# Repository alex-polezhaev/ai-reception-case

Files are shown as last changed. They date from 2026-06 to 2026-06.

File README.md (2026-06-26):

<div align="center">

# 🛎️ AI Reception

**A passive AI receptionist on an ESP32-S3.**
It quietly captures front-desk conversations, transcribes and analyzes them in the cloud, and turns each one into a structured report the manager reviews in a Telegram mini-app.







[Case study](docs/case-study.md) · [Architecture](#-architecture) · [Tech stack](#-tech-stack) · [Hardware](#-hardware--enclosure) · [Build & run](#-build--run) · [Author](#-author)

</div>

<div align="center">
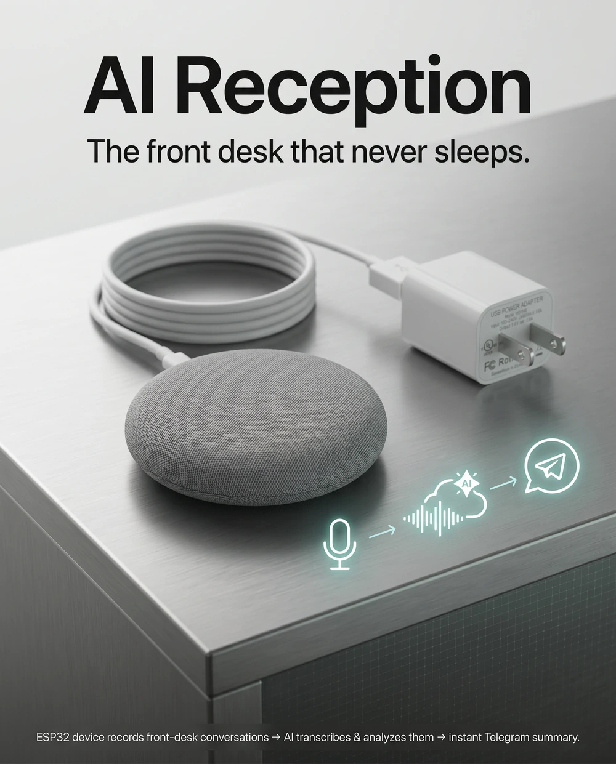
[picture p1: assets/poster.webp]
AI Reception, the front desk that never sleeps

</div>

---

## What it is

**AI Reception** is an end-to-end product: custom **firmware**, a cloud **backend**, and a 3D-printed **enclosure**, built and integrated by one engineer. A small ESP32-S3 device sits on a reception desk with a MEMS microphone. It detects speech on-device, captures audio in short raw-PCM chunks, and uploads them to a Swift/Vapor backend that reconstructs each conversation, transcribes and analyzes it with OpenAI, and presents a clean, structured report to the owner in a Telegram mini-app.

**Why it's interesting**

- 🎙️ **On-device voice activity detection**: the firmware runs an adaptive VAD, so only real speech is buffered and uploaded, never silence.
- 🧩 **Full-stack, multi-discipline**: embedded C++ firmware, a Swift/Vapor microservice backend, a Telegram mini-app, and printable CAD hardware in one coherent system.
- ☁️ **Discrete chunked upload**: fixed-length audio "slots" are POSTed over HTTP and reassembled into sessions server-side, then trimmed with Silero VAD before transcription. No persistent audio stream.
- 🤖 **Cloud AI**: OpenAI Whisper for transcription, an OpenAI LLM for summary and analysis.
- 🛠️ **Real hardware**: a custom 3D-printed round enclosure, shipped as editable CAD source.

---

## 🏗 Architecture

```mermaid
flowchart TB
    subgraph device["🛎️ Reception Device - 3D-printed enclosure"]
        MIC["I2S MEMS Microphone · 16 kHz PCM"]
        ESP["ESP32-S3 Firmware · C++ / PlatformIO<br/>Adaptive VAD · dual AudioSlot buffer"]
        MIC --> ESP
    end

    subgraph core["☁️ Core Backend - Swift / Vapor"]
        API["API Server<br/>JWT auth · POST /device/upload"]
        Q["pgmq message queue"]
        SW["Session Worker<br/>Silero VAD · silence trimming"]
        TW["Transcription Worker"]
        AW["Analysis Worker"]
        MA["Telegram Mini-App<br/>Leaf · HMAC auth"]
        API --> Q --> SW --> TW --> AW --> MA
    end

    STT["Whisper / Transcription"]
    LLM["LLM Analysis & Summary"]
    SB["🗄️ Supabase · Postgres + Auth"]
    S3["🗄️ S3 storage · PCM · WAV buckets"]
    OWNER["👤 Owner / Manager"]

    ESP -- "Wi-Fi · HTTP POST PCM chunks<br/>(per AudioSlot · octet-stream + JWT)" --> API
    ESP -. "silence notifications" .-> API
    API --> S3
    TW --> STT
    AW --> LLM
    API <--> SB
    MA -- "structured report" --> OWNER

    classDef hw fill:#ffe0b2,stroke:#e65100,color:#000;
    classDef ai fill:#e1f5fe,stroke:#0277bd,color:#000;
    class MIC,ESP hw;
    class STT,LLM,SW ai;
```

### How it works

1. **Capture.** The ESP32-S3 reads the I2S MEMS microphone at 16 kHz and fills fixed-length **AudioSlot** PCM buffers. An on-device **adaptive VAD** decides what counts as speech.
2. **Upload.** Each completed slot is sent as a discrete **HTTP POST of raw PCM** to `POST /device/upload/{device_id}` (`application/octet-stream`, `Bearer <JWT>`, with `X-Timestamp` / `X-Sample-Rate` / `X-Sample-Count` headers). Gaps are reported via `POST /device/silence`. *The device uploads chunks; it never holds an open audio stream.*
3. **Sessionize.** The Vapor **API Server** stores chunks in S3 and enqueues them on a Postgres `pgmq` queue. The **Session Worker** groups chunks into sessions and trims silence with **Silero VAD**.
4. **Understand.** The **Transcription Worker** runs **OpenAI Whisper**; the **Analysis Worker** runs an **OpenAI LLM** to produce a structured summary.
5. **Deliver.** The owner opens the **Telegram mini-app** to review a clean, structured report of each conversation.

---

## 🧰 Tech stack

| Layer | Technology |
|---|---|
| **Firmware** | ESP32-S3 · C++ · PlatformIO/Arduino · I2S audio · adaptive VAD · Wi-Fi captive portal |
| **Backend** | Swift · Vapor · async/await · JWT auth · `pgmq` queue |
| **AI** | OpenAI Whisper (transcription) · OpenAI LLM (analysis) · Silero VAD (silence trimming) |
| **Data** | Supabase (Postgres + Auth) · S3-compatible object storage |
| **Interface** | Telegram Bot + Mini-App (Leaf, HMAC auth) |
| **Hardware** | 3D-printed round enclosure (Shapr3D → STEP) |
| **Ops** | Docker Compose · nginx · Dozzle |

---

## 📁 Repository structure

```text
ai-reception-case/
├── firmware/      ESP32-S3 device firmware (C++ / PlatformIO)
├── core/          Swift / Vapor backend: API + workers + Telegram mini-app
├── hardware/      3D-printed round enclosure (STEP) + print notes
├── docs/          Case study (English) + screenshots + demo video
└── assets/        CAD renders and diagrams used in this README
```

---

## 🔩 Hardware & enclosure

The device lives in a custom 3D-printed round enclosure. Editable CAD source (`.step`) lives in [`hardware/`](hardware/).

<div align="center">
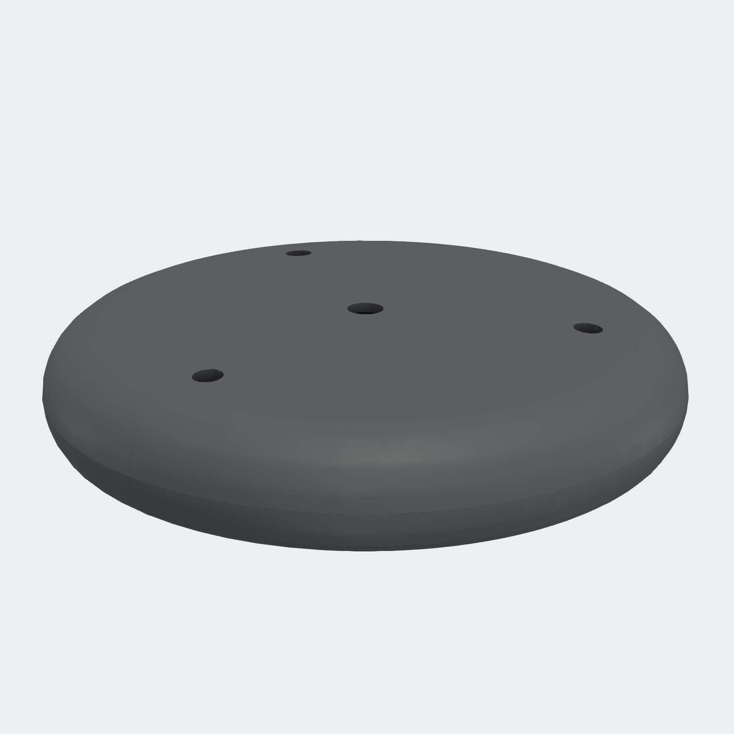
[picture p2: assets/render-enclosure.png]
Round enclosure, assembled

&nbsp;&nbsp;
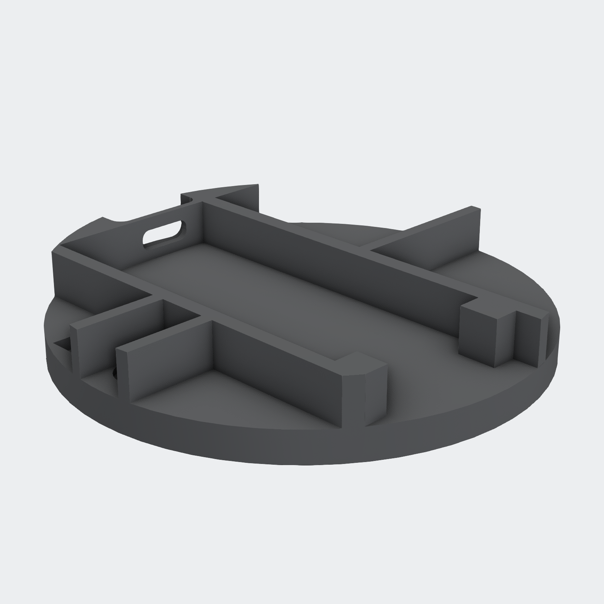
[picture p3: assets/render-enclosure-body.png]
Round enclosure, inside base

<br/>
<sub>The round enclosure (left) and its internal base that holds the board and microphone (right)</sub>
</div>

<div align="center">
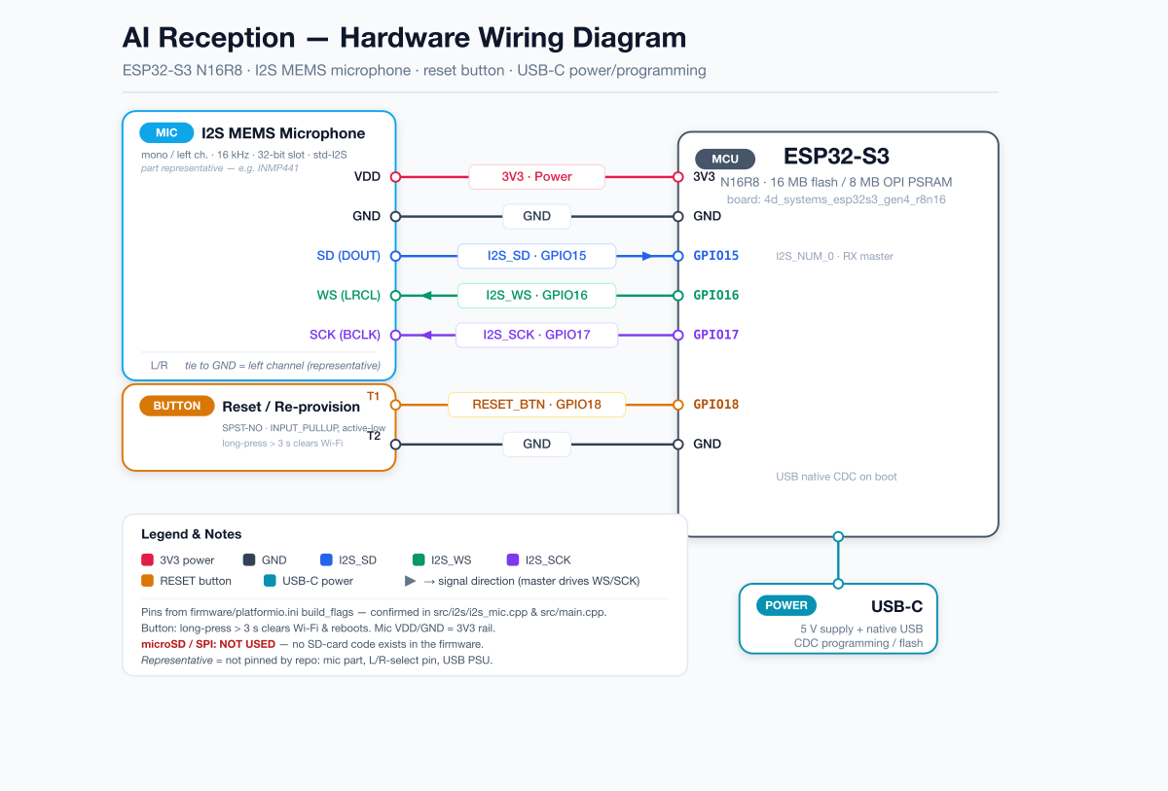
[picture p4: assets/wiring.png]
Hardware wiring diagram

<br/>
<sub>Wiring: I2S MEMS microphone + reset button on the ESP32-S3</sub>
</div>

| Part | File |
|---|---|
| Enclosure body (holds the board &amp; mic) | `hardware/enclosure/mic-v7-main.step` |
| Front cover (microphone hole) | `hardware/enclosure/mic-v7-case-mic-hole.step` |

See [`hardware/README.md`](hardware/README.md) for suggested print settings.

---

## 📸 Screenshots

### The Telegram mini-app

The manager reviews every conversation as a structured report: summary, quality score, keywords, products, audio playback, and the full transcript.

<table>
<tr>
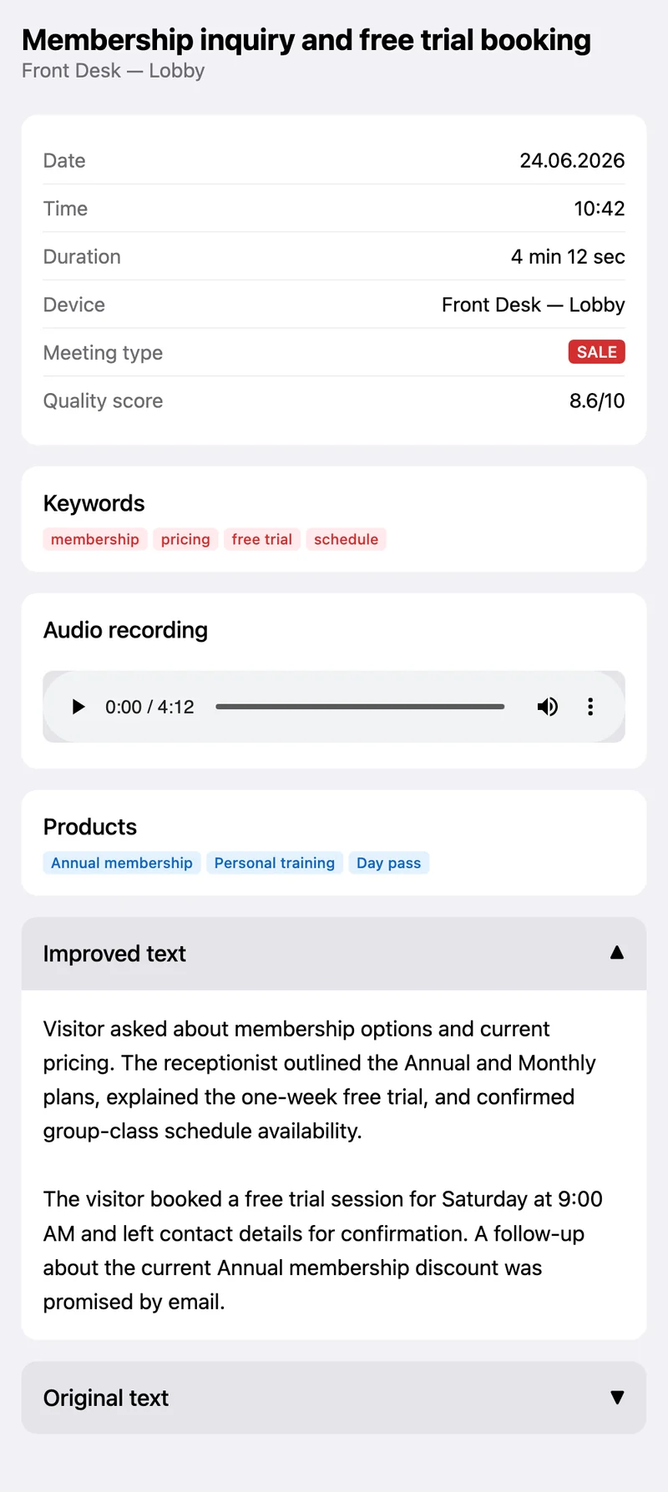
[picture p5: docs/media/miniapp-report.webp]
Session report
<td width="33%"><br/><sub>Session report: summary, quality score, keywords, audio</sub></td>
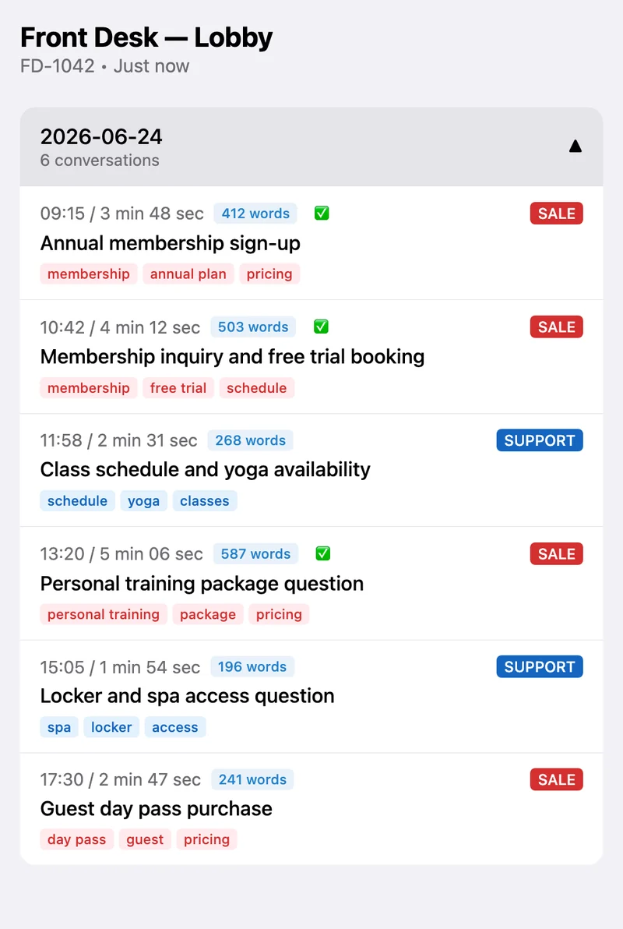
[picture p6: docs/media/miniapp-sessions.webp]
Conversation feed
<td width="33%"><br/><sub>Feed of analyzed conversations</sub></td>
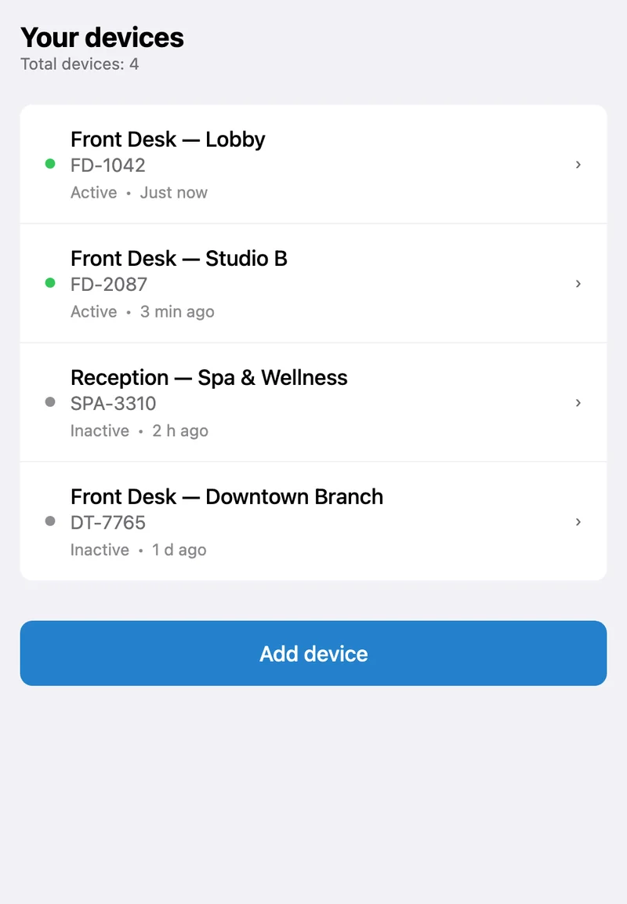
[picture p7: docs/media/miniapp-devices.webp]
Device fleet
<td width="33%"><br/><sub>Device fleet with live status</sub></td>
</tr>
</table>

### Hardware &amp; build

<table>
<tr>
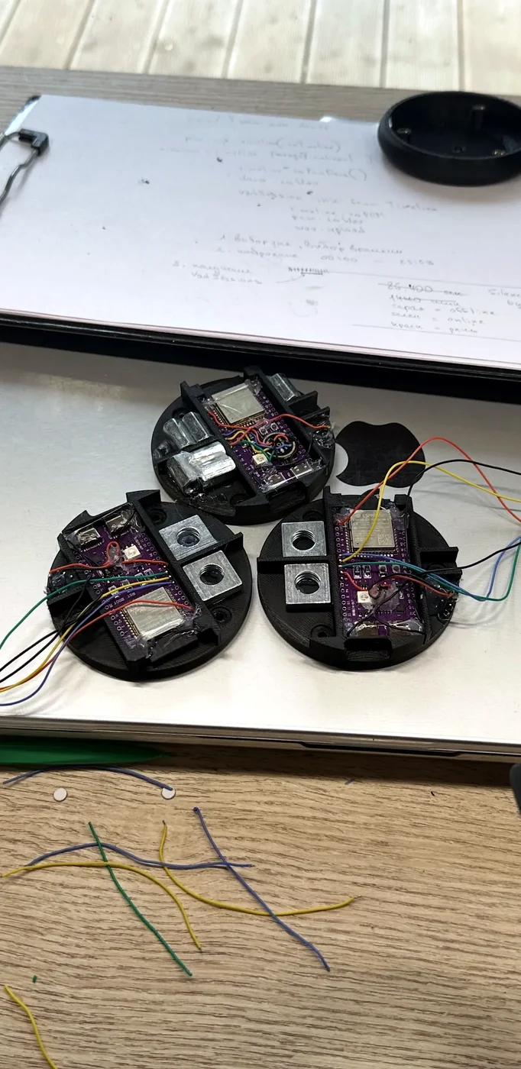
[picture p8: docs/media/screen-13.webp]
ESP32-S3 boards inside the enclosures
<td width="50%"><br/><sub>ESP32-S3 boards inside the printed enclosures</sub></td>
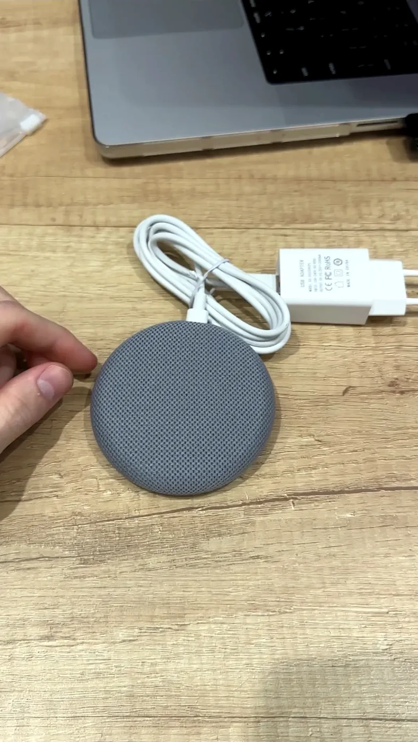
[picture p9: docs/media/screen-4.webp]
Assembled reception unit
<td width="50%"><br/><sub>The assembled reception unit</sub></td>
</tr>
<tr>
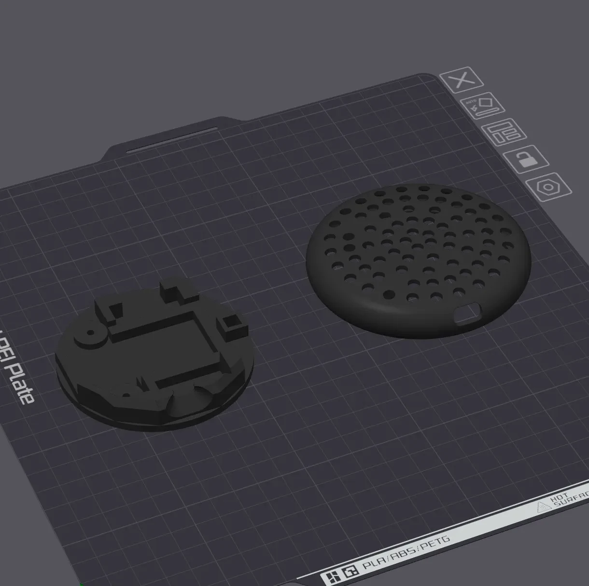
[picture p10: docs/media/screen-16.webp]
Enclosure parts in the slicer
<td width="50%"><br/><sub>Enclosure parts prepared for printing</sub></td>
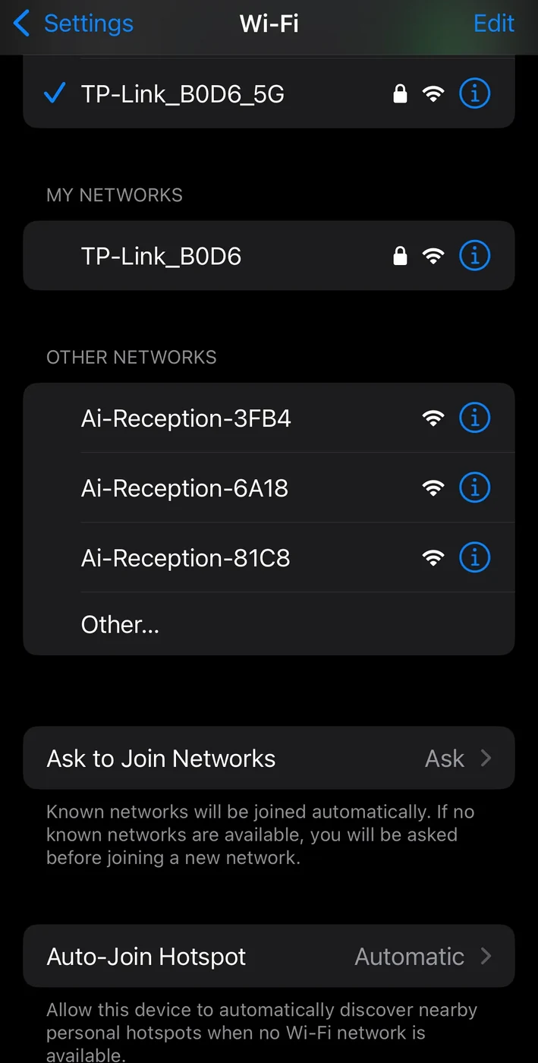
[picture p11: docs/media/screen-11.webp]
Wi-Fi captive-portal setup
<td width="50%"><br/><sub>Captive-portal Wi-Fi setup (<code>Ai-Reception-&lt;id&gt;</code>)</sub></td>
</tr>
</table>

A full walkthrough, including the transcript view, is in the [case study](docs/case-study.md).

---

## 🚀 Build & run

<details>
<summary><b>Firmware: ESP32-S3 (PlatformIO)</b></summary>

```bash
cd firmware
# set your backend URL and device id, then build & flash:
SERVER_URL="https://core.your-domain.example" DEVICE_ID="reception-01" \
  pio run -t upload
```

On first boot the device exposes a Wi-Fi access point (`Ai-Reception`) with a captive portal for entering Wi-Fi credentials. See [`firmware/README.md`](firmware/README.md).
</details>

<details>
<summary><b>Backend: Swift / Vapor (Docker Compose)</b></summary>

```bash
cd core
cp .env.example .env      # fill in OpenAI / Supabase / S3 / Telegram values
make create-network && make docker-build-prod   # build & run the stack
```

Device endpoints: `/device/boot`, `/device/upload`, `/device/silence`, `/device/log`. See [`core/README.md`](core/README.md).
</details>

---

## 🗺 Roadmap

- [x] ESP32-S3 firmware with on-device adaptive VAD
- [x] Discrete chunked PCM upload pipeline
- [x] Swift/Vapor backend: transcription + analysis workers
- [x] Telegram bot + mini-app reports
- [x] 3D-printed round enclosure
- [ ] OTA firmware updates
- [ ] Multi-device fleet dashboard
- [ ] On-device wake-word gating

---

## 🧭 Project evolution

AI Reception went through three hardware generations: a **Gen-1** ESP32 prototype (ESP-IDF / C), an intermediate **Raspberry Pi** attempt, and the current **Gen-2** ESP32-S3 device (PlatformIO / C++) shown here. This repo presents the current system only; earlier branches were retired to keep the design focused.

---

## 📄 License

Released under the [MIT License](LICENSE).

---

## 👤 Author

**Alex Polezhaev**, full-stack & embedded engineer.
I build end-to-end products across firmware, cloud backends, and hardware. **Relocating to the United States, open to roles.**

- GitHub: [@alex-polezhaev](https://github.com/alex-polezhaev)
- Email: polezhaev.advert@gmail.com

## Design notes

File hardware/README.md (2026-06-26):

# Hardware - enclosure

3D-printable parts for the ESP32-S3 reception microphone device: the round enclosure that houses the board and microphone.

## Overview

The physical device is housed in a single round **enclosure** made of two parts: a **body** that holds the ESP32-S3 board and microphone, and a **cap / front cover** with the microphone hole. Files are provided as `.step` parametric CAD sources for editing/remixing. Renders are in [`../assets/`](../assets/).

## Tech / stack

- **`.step`**: parametric CAD source, a neutral exchange format that imports into any CAD tool (Fusion 360, FreeCAD, SolidWorks, Onshape, etc.).

## Structure

```
hardware/
└── enclosure/
    ├── mic-v7-main.step           # Round body - holds the ESP32-S3 board and microphone
    └── mic-v7-case-mic-hole.step  # Cap / front cover with the microphone hole
```

## Build & run

Open a `.step` file in your CAD tool to edit or remix, then export a mesh to your slicer to print. Suggested starting settings for FDM printing (tune to your printer and material):

- **Material:** PLA
- **Layer height:** ~0.2 mm
- **Infill:** 15-20%
- **Supports:** as needed (depends on part orientation)

These are suggested defaults, not strict requirements. Adjust orientation, supports, and infill to suit your printer.

---

[← project root](../README.md)

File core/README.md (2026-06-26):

# Core: backend (the "brain")

Swift/Vapor backend that turns raw audio captured by edge devices into a structured, human-readable report delivered over Telegram.

## Overview

Edge devices send raw PCM audio chunks to the API. The backend groups those chunks into conversation sessions, trims silence, transcribes the speech, runs an LLM analysis, and pushes the resulting structured report to the operator through a Telegram Mini App and bot. Work is passed between stages over a Postgres-backed message queue (**PGMQ**): `session-queue`, `transcription-queue`, `analysis-queue`.

Pipeline components:

- **APIServer**: Vapor HTTP API. Authenticates devices via JWT, ingests PCM audio chunks and device events, and enqueues work.
- **SessionWorker**: Groups incoming PCM chunks into sessions and uses **Silero VAD** to detect speech and trim silence, producing a clean session WAV.
- **TranscriptionWorker**: Sends session audio to **OpenAI Whisper** for speech-to-text.
- **AnalysisWorker**: Runs an **OpenAI LLM** over the transcript to produce a structured summary / analysis.
- **MiniApp**: Telegram Mini App + bot (Vapor + Leaf templates, HMAC verification of Telegram init data) that delivers the report to the operator.

Transcription and analysis run on the OpenAI cloud API; only Silero VAD runs locally as an internal service.

Device endpoints: `GET /device/boot/:deviceid` (handshake, issues the device JWT), `POST /device/upload/:deviceid` (PCM chunk), `POST /device/silence/:deviceid`, `POST /device/log/:deviceid`. All but `boot` are authenticated with the device JWT (Bearer token) and validate the device ID.

Storage: **Supabase** Postgres (schema, sessions, devices, logs; PGMQ lives inside Postgres) plus **S3-compatible** object storage with separate buckets for raw device PCM (`S3_DEVICE_PCM_BUCKET`) and processed session WAV (`S3_SESSIONS_WAV_BUCKET`).

## Tech / stack

- Swift 6.1 / Vapor 4, SwiftPM (see `workers/Package.swift`)
- Leaf templates for the Telegram Mini App
- Supabase Swift, Soto (S3), AsyncHTTPClient, swift-crypto, JWT
- Silero VAD service (Python, `silero-vad/`)
- docker-compose per service, orchestrated via the root `Makefile`
- Configuration via `.env` (copy from `.env.example`)

## Structure

```
core/
├── workers/          # Swift/Vapor sources (APIServer, MiniApp, *Worker, Shared)
│   ├── Sources/
│   ├── Resources/    # Leaf templates for the Telegram Mini App
│   └── Package.swift
├── silero-vad/       # Silero VAD service (Python) + Dockerfile
├── supabase/         # Supabase config, migrations, seed
├── nginx/            # Reverse proxy
├── dozzle/           # Log viewer
├── portainer/        # Container management
├── Makefile          # docker-compose orchestration
└── .env.example      # Environment template
```

## Build & run

1. Copy the example environment file and fill in real values (all secrets in `.env.example` are placeholders):

   ```sh
   cp .env.example .env
   # edit .env
   ```

2. Build the Swift workers locally with SwiftPM (from `workers/`):

   ```sh
   cd workers
   swift build -c release
   ```

3. Or run the full stack with docker-compose via the `Makefile`:

   ```sh
   make create-network
   make docker-build-prod
   ```

   Individual services can be brought up with the per-service targets
   (`build-workers-prod`, `build-silero-vad-prod`, `build-nginx-prod`, etc.).

---

[← project root](../README.md)

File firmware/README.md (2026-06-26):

# Firmware - ESP32-S3 reception device

ESP32-S3 firmware that captures room audio, detects speech on-device, and uploads recorded PCM chunks to the backend over HTTP.

## Overview

The device samples an I2S MEMS microphone at 16 kHz and runs an **adaptive VAD** (Voice Activity Detector) that continuously adapts to the ambient noise floor to separate speech from silence. Detected speech fills fixed-length PCM buffers (**AudioSlots**) allocated in PSRAM; each completed slot is uploaded as a discrete `application/octet-stream` HTTP POST to `/device/upload/{DEVICE_ID}`. It does **not** stream audio. When no speech is detected, the device reports a silence interval instead.

On first boot (or after pressing the reset button) the device exposes an open Wi-Fi access point (`Ai-Reception-<DEVICE_ID>`) with a **captive portal** for Wi-Fi provisioning; credentials are stored on-device for subsequent boots. At boot it authenticates against the backend and obtains a Bearer JWT used for all subsequent requests.

Backend device endpoints used: `/device/boot`, `/device/upload/{DEVICE_ID}`, `/device/silence`, `/device/log`.

## Tech / stack

- [PlatformIO](https://platformio.org/) + Arduino framework
- Board: `4d_systems_esp32s3_gen4_r8n16` (ESP32-S3 **N16R8**, 16 MB flash / 8 MB PSRAM); environment `esp32-s3-n16r8`
- [`tzapu/WiFiManager`](https://github.com/tzapu/WiFiManager) - Wi-Fi captive portal
- [`bblanchon/ArduinoJson`](https://github.com/bblanchon/ArduinoJson) - JSON encoding

## Structure

```
firmware/
├── platformio.ini        # board, build flags, dependencies
├── Makefile              # dev / prod / erase convenience targets
└── src/
    ├── main.cpp          # entry point, main loop
    ├── audio/            # AudioSlots + adaptive VAD
    ├── i2s/              # I2S MEMS microphone driver
    ├── server/           # backend HTTP API client
    ├── boot/             # boot-time authentication
    └── portal/           # Wi-Fi captive portal
```

Pin assignments and several runtime parameters (sample rate, GPIOs, server URL, device ID) are wired through `build_flags` in [`platformio.ini`](./platformio.ini). Note that some values listed there (`MAX_UPLOAD_RETRIES`, `MIN_BUFFER_SLOTS`, `MAX_BUFFER_SLOTS`, `PSRAM_USAGE_PERCENT`, `I2S_BUFFER_SAMPLES`, `WIFI_AP_SSID`) are **compile-time constants defined in source** and are not actually read from the build flags; changing those flags has no effect without editing the code.

## Build & run

Built with PlatformIO. Two environment variables are injected into the firmware at build time via `${sysenv.*}`:

| Env var | Description | Example |
|---|---|---|
| `SERVER_URL` | Base URL of the backend | `https://core.your-domain.example` |
| `DEVICE_ID` | Unique identifier for this device | `desk-01` |

Build and flash directly:

```bash
SERVER_URL="https://core.your-domain.example" \
DEVICE_ID="desk-01" \
pio run -e esp32-s3-n16r8 -t upload
```

Or use the `Makefile` convenience targets (`DEVICE_ID` is required):

```bash
make dev  DEVICE_ID="desk-01"   # builds against the local dev SERVER_URL
make prod DEVICE_ID="desk-01"   # builds against the production SERVER_URL
make erase                      # full flash erase
```

Serial monitor runs at `115200` baud; upload speed is `921600`.

---

[← project root](../README.md)

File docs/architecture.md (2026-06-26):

# AI Reception: Technical Architecture

> Deep-dive technical reference for the AI Reception system.
> For the high-level overview, screenshots, and build instructions, see the
> [root README](../README.md). For the product narrative, see the
> [case study](case-study.md).

This document describes the end-to-end system: how a passive ESP32-S3 desk
device captures front-desk conversations, how those conversations travel through
the Swift/Vapor cloud backend, and how the owner receives a structured report on
Telegram. Everything below is derived directly from the firmware and backend
source. Where a value or behavior is named, it is taken from the code, not
assumed.

---

## 1. System overview

AI Reception is a three-part product:

| Layer | Runtime | Responsibility |
|---|---|---|
| **Device (edge)** | ESP32-S3 · C++ / PlatformIO + Arduino | Capture mic audio, run on-device VAD, upload speech as discrete PCM chunks over HTTP |
| **Core (cloud)** | Swift 6.1 · Vapor 4 · Docker Compose | Authenticate devices, ingest PCM, sessionize, trim silence, transcribe, analyze, deliver |
| **Storage / AI** | Supabase Postgres + PGMQ · S3 buckets · OpenAI cloud · Silero VAD service | Persistence, queueing, transcription, and LLM analysis |

The defining design property: **the device does not stream audio.** It records
fixed-length 60-second PCM buffers (`AudioSlot`s) and uploads each one as a
separate, self-contained HTTP `POST`. The backend reassembles those chunks into
conversation sessions server-side.

---

## 2. Architecture diagram

The following Mermaid diagram is reproduced verbatim from the [root README](../README.md):

```mermaid
flowchart TB
    subgraph device["🛎️ Reception Device - 3D-printed enclosure"]
        MIC["I2S MEMS Microphone · 16 kHz PCM"]
        ESP["ESP32-S3 Firmware · C++ / PlatformIO<br/>Adaptive VAD · dual AudioSlot buffer"]
        MIC --> ESP
    end

    subgraph core["☁️ Core Backend - Swift / Vapor"]
        API["API Server<br/>JWT auth · POST /device/upload"]
        Q["pgmq message queue"]
        SW["Session Worker<br/>Silero VAD · silence trimming"]
        TW["Transcription Worker"]
        AW["Analysis Worker"]
        MA["Telegram Bot + MiniApp<br/>Leaf · HMAC auth"]
        API --> Q --> SW --> TW --> AW --> MA
    end

    STT["Whisper / Transcription"]
    LLM["LLM Analysis & Summary"]
    SB["🗄️ Supabase · Postgres + Auth"]
    S3["🗄️ S3 storage · PCM · WAV buckets"]
    OWNER["👤 Owner / Manager"]

    ESP -- "Wi-Fi · HTTP POST PCM chunks<br/>(per AudioSlot · octet-stream + JWT)" --> API
    ESP -. "silence notifications" .-> API
    API --> S3
    TW --> STT
    AW --> LLM
    API <--> SB
    MA -- "structured report" --> OWNER

    classDef hw fill:#ffe0b2,stroke:#e65100,color:#000;
    classDef ai fill:#e1f5fe,stroke:#0277bd,color:#000;
    class MIC,ESP hw;
    class STT,LLM,SW ai;
```

---

## 3. End-to-end data flow

### 3.1 Device capture

- The firmware boots, provisions Wi-Fi via a captive portal (`WiFiManager`,
  AP SSID `Ai-Reception-<DEVICE_ID>`), then calls `boot_auth()` to obtain a JWT and the
  server's wall-clock time, which it writes into the system clock with
  `settimeofday()` (`boot/boot_auth.cpp`). Accurate time is essential because
  every chunk is keyed by its capture timestamp.
- Audio runs on two FreeRTOS tasks pinned to separate cores
  (`audio/audio_system.cpp`):
  - **Capture task** (core 0, priority 5) - fills the `record_slot`.
  - **Upload task** (core 1, priority 3) - drains the `upload_slot`.
- The I2S MEMS microphone is read at **16 kHz, 32-bit slots, left channel only**
  (`i2s/i2s_mic.cpp`, `I2S_CHANNEL_FMT_ONLY_LEFT`). Each raw 32-bit sample is
  DC-blocked with a one-pole high-pass (`alpha_ = 0.995`), right-shifted by 11
  (`>> 11`, an effective volume boost), clamped to int16 range, and stored as
  **16-bit PCM**. So the wire format is 16-bit even though the I2S slot width is
  32-bit.

### 3.2 Adaptive VAD (on-device)

- `AdaptiveVAD` (`audio/adaptive_vad.h` / `.cpp`) decides speech vs. silence per
  frame using **energy** and **zero-crossing rate (ZCR)** features against a
  continuously-adapted background model.
- Key parameters (from `adaptive_vad.h`): `CALIBRATION_SAMPLES = 500`,
  `BACKGROUND_HISTORY = 1000`, `CHANGE_THRESHOLD = 3.0` sigma,
  `ZCR_MIN = 0.03` / `ZCR_MAX = 0.4`, `MIN_SPEECH_FRAMES = 3`, and an hourly
  recalibration (`RECALIB_INTERVAL = 3600000 ms`). State machine:
  `VAD_CALIBRATING → VAD_RUNNING → VAD_RECALIBRATING`.
- VAD runs **while** the slot is filling. As soon as any frame in a slot is
  classified as speech, the whole 60-second slot is flagged
  `has_speech = true`. The VAD here is a coarse on-device gate; precise
  trimming happens server-side with Silero.

### 3.3 AudioSlot (dual-buffer, chunked)

- Two slots are allocated in **PSRAM** (`init_audio_memory()`), each sized
  `I2S_SAMPLE_RATE * AUDIO_RECORD_DURATION_SEC * sizeof(int16_t)` =
  `16000 * 60 * 2` = **1,920,000 bytes (~1.83 MB)** holding 960,000 samples.
- The capture task records exactly 60 s into `record_slot`, then copies it into
  `upload_slot` and marks it ready (`used = false`). A timing compensation keeps
  the cycle on a fixed `RECORD_INTERVAL_MS = 60000` ms cadence.
- The upload task branches on `has_speech`:
  - **Speech** → `upload_audio_slot()` (`POST /device/upload/...`), up to 5
    retries; on total failure it reboots (`ESP.restart()`).
  - **Silence** → `upload_silence_notification()` (`POST /device/silence/...`),
    up to 3 retries; on total failure it reboots.

> Note on retry counts: `platformio.ini` defines `MAX_UPLOAD_RETRIES=3` /
> `UPLOAD_RETRY_DELAY_MS=5000`, but the audio upload loop in
> `audio_system.cpp` is hard-coded to **5 attempts with a 3 s delay** (silence:
> 3 attempts / 2 s). The hard-coded values are what actually run.

### 3.4 HTTP POST PCM chunk → API

Each speech slot is sent as one `POST /device/upload/{DEVICE_ID}` with
`Content-Type: application/octet-stream`, `Authorization: Bearer <JWT>`, and the
`X-Timestamp` / `X-Sample-Rate` / `X-Sample-Count` headers
(`server/server_api.cpp`). The body is the raw little-endian int16 PCM.

The Vapor `DeviceController.upload` (`APIServer/Controllers/DeviceController.swift`):

1. Verifies the JWT and that `payload.device_id == :deviceid`.
2. Reads `X-Timestamp` and streams the request body into a `Data` buffer.
3. **Validates size**: must equal
   `sampleRate * channels * (bitsPerSample/8) * duration` =
   `16000 * 1 * 2 * 60` = **1,920,000 bytes** (`Shared/Utils/AudioConfig.swift`).
   Wrong size → `400`.
4. **Runs Silero VAD first** (see 3.5). If the returned 60-element mask contains
   no `1`, the chunk is treated as silence: a `SilenceChunk` is upserted, the
   device's `bad_vad_count` is incremented, and the audio is **not** stored.
5. If speech is present, the PCM is uploaded to S3 under
   `{deviceId}/{unixTimestamp}.pcm` (bucket `S3_DEVICE_PCM_BUCKET`), and a
   `pcm_chunks` row is upserted (on conflict `s3_key`) carrying the full
   `vad_timeline` array.

### 3.5 Server-side Silero VAD gate (in the API request)

`SileroVADService` (`APIServer/Utils/SileroVADService.swift`) converts the PCM
to an `Int` array and `POST`s it to the Python Silero service (`SILERO_VAD_URL`,
`/vad`). The service (`silero-vad/main.py`, FastAPI + `snakers4/silero-vad`)
expects exactly 960,000 samples, normalizes to `[-1, 1]`, runs
`get_speech_timestamps` (`threshold=0.5`, `min_speech_duration_ms=250`,
`min_silence_duration_ms=100`, `window_size_samples=1024`, `speech_pad_ms=30`),
and returns a **60-element binary mask, one entry per second**. If the Silero
call is non-200, the Swift side falls back to a 60-zero mask (treated as
silence). This is a second, more accurate gate that runs *before* anything is
persisted, saving storage and downstream compute on the device's coarse VAD
false-positives.

### 3.6 pgmq → SessionWorker → TranscriptionWorker → AnalysisWorker

Stages hand off through **PGMQ** (Postgres-backed queue) using
`pgmqGet`/`pgmqAck` RPCs against schema `pgmq_public` (`Shared/Supabase/Pgmq.swift`).
Three queues: **`session-queue`**, **`transcription-queue`**, **`analysis-queue`**.

- **SessionWorker** (`Sources/SessionWorker`): groups contiguous `pcm_chunks`
  into conversation **sessions**, uses Silero VAD timelines to trim silence, and
  produces a clean session WAV (stored in `S3_SESSIONS_WAV_BUCKET`). Supporting
  logic lives in `src/ProcessTimeline.swift`, `SessionTimelines.swift`,
  `TimelineExtensions.swift`, `BeautifySession.swift`.
- **TranscriptionWorker** (`Sources/TranscriptionWorker`): sends the session
  WAV to **OpenAI Whisper** (`Shared/OpenAI/WhisperService.swift`) for
  speech-to-text.
- **AnalysisWorker** (`Sources/AnalysisWorker`): runs an **OpenAI LLM** over the
  transcript (`Shared/OpenAI/OpenAIClient.swift`, `PromptService.swift`,
  stored prompt IDs in `PromptIDs.swift`) to produce a structured summary /
  analysis (`vad_analysis`).

### 3.7 Delivery (Telegram)

The **MiniApp** (`Sources/MiniApp`) is a Vapor + **Leaf** app serving a Telegram
Mini App and bot. It verifies Telegram `initData` via **HMAC**
(`MiniApp/Middleware/TelegramAuthMiddleware.swift`) and renders session reports
(summary, quality score, keywords, transcript) from Leaf templates in
`workers/Resources/Views/`. The owner opens the Telegram Mini App to review the
structured report of each conversation.

---

## 4. Device HTTP API

Base URL is the build-time `SERVER_URL`; device id is the build-time `DEVICE_ID`.
All routes are registered in `DeviceController.boot(routes:)`. `boot` is
unauthenticated and issues the JWT; the other three require
`Authorization: Bearer <JWT>` and enforce that the token's `device_id` matches
the `:deviceid` path parameter.

### `GET /device/boot/{deviceid}`

- **Auth:** none (this is where the JWT is issued).
- **Behavior:** looks up the device in Supabase, signs a `DevicePayload` JWT,
  sets `boot_at` / `last_active_at` (and `activated_at` on first boot).
- **Response:** `{"jwt": "<token>", "time": <unix_seconds>}`. The firmware uses
  `time` to set its clock.

### `POST /device/upload/{deviceid}`

- **Headers:** `Content-Type: application/octet-stream`,
  `Authorization: Bearer <JWT>`, `X-Timestamp` (unix seconds, slot capture
  time), `X-Sample-Rate` (`16000`), `X-Sample-Count` (`960000`).
- **Body:** raw little-endian int16 PCM, exactly **1,920,000 bytes**.
- **Behavior:** JWT + device check → size/format validation → Silero VAD gate →
  S3 upload + `pcm_chunks` insert (speech) or `silence_chunks` insert +
  `bad_vad_count++` (no speech).
- **Response:** `200 OK` (`"OK"` or `"OK - No voice activity detected"`); `400`
  on bad size/format; `401`/`403` on auth failure.

### `POST /device/silence/{deviceid}`

- **Headers:** `Content-Type: application/json`,
  `Authorization: Bearer <JWT>`, `X-Timestamp`.
- **Body:** empty (the firmware sends `""`).
- **Behavior:** upserts a `silence_chunks` row (on conflict `device_id,timestamp`)
  and bumps `last_active_at`. This is the device telling the server "this
  60-second slot had no speech, no audio uploaded."
- **Response:** `200 OK`.

### `POST /device/log/{deviceid}`

- **Headers:** `Content-Type: application/json`, `Authorization: Bearer <JWT>`.
- **Body:** `{"level": "<error|warn|info|...>", "message": "<text>"}`.
- **Behavior:** inserts an `AppLog` row with `source = deviceId`. The firmware
  uses this on the next boot after a crash (`check_and_send_crash_log()` detects
  `ESP_RST_PANIC` / `ESP_RST_WDT` / `ESP_RST_BROWNOUT`).
- **Response:** `200 OK`.

---

## 5. Data model & storage

### 5.1 Supabase Postgres

Tables (from `core/supabase/migrations/`):

| Table | Purpose |
|---|---|
| `devices` | Device registry: `id`, `boot_at`, `last_active_at`, `activated_at`, `bad_vad_count`, `incomplete_timestamp` |
| `pcm_chunks` | One row per stored speech slot: `s3_key`, `timestamp`, `duration`, `device_id`, `vad_timeline` |
| `silence_chunks` | One row per silent slot (unique on `device_id,timestamp`) |
| `vad_sessions` | Reassembled conversation sessions |
| `vad_transcriptions` | Whisper transcripts per session |
| `vad_analysis` | LLM summary / structured analysis per session |
| `telegram_accounts`, `telegram_account_devices` | Owner ↔ device mapping for the Mini App |
| `logs` | Device and service logs |
| `proxies` | Outbound proxy config |

PGMQ lives inside the same Postgres instance (schema `pgmq_public`), providing
the `session-queue`, `transcription-queue`, and `analysis-queue`.

### 5.2 S3 object storage

| Bucket env | Contents | Key pattern |
|---|---|---|
| `S3_DEVICE_PCM_BUCKET` (`device-pcm`) | Raw per-slot int16 PCM uploaded from devices | `{deviceId}/{unixTimestamp}.pcm` |
| `S3_SESSIONS_WAV_BUCKET` (`sessions-wav`) | Cleaned, silence-trimmed session WAVs produced by SessionWorker | session-keyed |
| `S3_INCOMPLETE_TIMELINE_BUCKET` | Partial/in-progress timelines | - |

Access is via Soto S3 (`Shared/Utils/S3Wrapper.swift`).

---

## 6. Key design decisions

### Chunked HTTP upload vs. continuous streaming

The device deliberately **uploads discrete 60-second PCM chunks** instead of
holding an open audio stream. Reasons evident in the code:

- **Resilience over a flaky desk Wi-Fi link.** Each `AudioSlot` is a complete,
  independently-retryable unit (5 retries for audio, 3 for silence). A dropped
  connection costs at most one chunk, not the whole conversation; the firmware
  reboots cleanly if a chunk can't be delivered.
- **Simple, stateless ingestion.** The API server handles each POST in
  isolation (validate → VAD → store → enqueue) with no long-lived socket or
  backpressure to manage. Sessionization is deferred to an offline worker.
- **Cheap silence.** Slots with no speech are reported with an empty-body
  `/device/silence` call (or rejected by the server VAD) and never touch S3,
  far less traffic than streaming continuous audio.
- **Bounded device memory.** Two PSRAM slots (record + upload) are enough; the
  device never needs to buffer an entire conversation.

Trade-off: up to ~60 s of latency before a chunk is even sent, and
conversations are reconstructed from fixed slot boundaries rather than natural
speech turns, which is exactly what SessionWorker's timeline logic exists to
smooth out.

### On-device VAD vs. server VAD (both, in sequence)

The system runs VAD **twice**, on purpose:

- **On-device adaptive VAD** is a cheap, coarse gate. Its only job is to avoid
  uploading obviously-silent slots, saving uplink bandwidth and server compute.
  It runs on energy + ZCR with a self-calibrating noise floor so it adapts to
  each room without tuning.
- **Server-side Silero VAD** is the accurate gate and the trimming engine. It
  produces a per-second speech mask used both to reject false-positive uploads
  *before* persistence and to trim silence when building session WAVs.

Putting the precise model in the cloud keeps the firmware small and
power-friendly, while the on-device gate keeps the cloud from paying for the
device's silence. The `bad_vad_count` on each device records how often the
device's coarse VAD disagreed with Silero, a built-in quality signal for the
on-device threshold.

---

## 7. Cross-references

- [Root README](../README.md): overview, diagram source, build & run.
- [`firmware/README.md`](../firmware/README.md): device firmware, pin map, build flags.
- [`core/README.md`](../core/README.md): backend components, endpoints, storage.
- [`hardware/README.md`](../hardware/README.md): enclosure, print settings.
- [`hardware/BOM.md`](../hardware/BOM.md): bill of materials (reference).
- [Case study](case-study.md): product narrative and walkthrough.

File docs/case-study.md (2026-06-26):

# AI Reception: A Passive Conversation-Intelligence Appliance for Small Business

A small, always-on device sits on a reception desk and passively records every customer
conversation. The audio is automatically transcribed and analyzed by AI, and the business
owner opens a Telegram mini-app to review a structured report of each conversation, no staff
involvement, no manual review.

It is a full vertical slice of product engineering: custom **ESP32-S3 firmware** (C++ /
PlatformIO) with on-device voice activity detection, a **Swift / Vapor** backend built as a
queue-driven pipeline, **OpenAI Whisper + LLM** in the cloud for transcription and analysis,
a **Telegram Bot + MiniApp** for management and delivery, and **3D-printed enclosures** for
the physical device.

The AI Reception device, a 3D-printed microphone appliance

---

## The problem

The owner of a small business (a clinic, a salon, a fitness club, a service shop) is rarely
standing at the front desk. As a result they have no visibility into what actually happens
there:

- what was discussed with each customer
- why a customer left without booking
- which questions come up most often
- how staff actually talk to people

Hiring someone to listen to recordings is expensive. Listening personally is impossible at
scale. **AI Reception does it automatically**: it listens, transcribes, extracts the essence,
and turns it into a concise summary the owner can read in seconds.

---

## Solution at a glance

1. A device on the desk captures audio and runs **voice activity detection on-chip**, so only
   speech leaves the device.
2. Speech is uploaded as **discrete PCM chunks over HTTP** to the backend.
3. A chain of independent **Swift workers** trims silence, transcribes with **Whisper**, and
   analyzes the transcript with an **OpenAI LLM**.
4. The result (who the customer was, why they came, what they asked, the outcome) is
   available to the owner as a structured report in the **Telegram MiniApp**.

The Telegram mini-app session report: summary, quality score, keywords, products and audio playback

---

## System architecture

```
┌──────────────────────────── DEVICE (ESP32-S3, C++/PlatformIO) ────────────────────────────┐
│  I2S MEMS mic @16 kHz → DMA → Adaptive VAD (on-chip) → fixed-length AudioSlot PCM buffers   │
│                                          │                                                  │
│            speech chunks: HTTP POST /device/upload/{device_id}  (octet-stream + JWT)        │
│            silence events: HTTP POST /device/silence                                        │
└──────────────────────────────────────────┼────────────────────────────────────────────────┘
                                            │
                              ┌─────────────▼─────────────┐
                              │  CORE - Swift / Vapor      │
                              │  APIServer                 │
                              │  • verify JWT              │
                              │  • store PCM → S3 bucket    │
                              │  • write chunk metadata     │
                              │  • detect session boundary  │
                              └─────────────┬─────────────┘
                                            │  enqueue (Supabase pgmq)
                                            ▼
                              ┌───────────────────────────┐
                              │  SessionWorker             │
                              │  • gather session PCM       │
                              │  • Silero VAD silence trim  │
                              │  • assemble WAV → S3 bucket │
                              └─────────────┬─────────────┘
                                            ▼  transcription queue
                              ┌───────────────────────────┐
                              │  TranscriptionWorker       │
                              │  • OpenAI Whisper (cloud)   │
                              └─────────────┬─────────────┘
                                            ▼  analysis queue
                              ┌───────────────────────────┐
                              │  AnalysisWorker            │
                              │  • OpenAI LLM (cloud)       │
                              │  • structured JSON report   │
                              └─────────────┬─────────────┘
                                            ▼
                              ┌───────────────────────────┐
                              │  Telegram Bot + MiniApp    │
                              │  structured session report │
                              └───────────────────────────┘

Storage: Supabase (Postgres + Auth) · S3-compatible buckets (raw PCM, assembled WAV)
Queue:   Supabase pgmq (Postgres message queue) - no Redis, no Kafka
```

The pipeline is deliberately decomposed into small, independent processes connected by a
**Postgres-native message queue (pgmq)**. Each worker reads one message, does one job, and
publishes the next message. A crash in any single worker does not bring down the system - the
message simply stays on its queue and is retried.

---

## The device: ESP32-S3 firmware (C++ / PlatformIO)

The current device is built on the **ESP32-S3** (Xtensa LX7, 8 MB PSRAM, native USB) using
**PlatformIO** for a comfortable, library-rich workflow. A digital **I2S MEMS microphone**
feeds the chip directly.

Device internals: ESP32 boards wired inside the 3D-printed bases

### I2S audio capture

Capture parameters are tuned for intelligible speech at minimal bandwidth:

- **16 kHz sample rate**, the practical minimum for clear speech through Whisper
- **16-bit PCM, mono**, the standard input for speech-to-text
- **DMA double buffering**, I2S reads into a ring buffer via DMA, so the CPU never blocks
  waiting on samples

### Adaptive VAD: speech detection on-chip

A custom C++ voice-activity detector runs on every buffer *before* anything is uploaded. It
combines two cheap, real-time features:

```cpp
class AdaptiveVAD {
  float energyThreshold;  // dynamic RMS threshold
  float zcrThreshold;     // dynamic zero-crossing threshold

  float computeRMS(int16_t* samples, size_t n) {
    float sum = 0;
    for (size_t i = 0; i < n; i++)
      sum += (float)samples[i] * samples[i];
    return sqrtf(sum / n);
  }

  float computeZCR(int16_t* samples, size_t n) {
    int crossings = 0;
    for (size_t i = 1; i < n; i++)
      if ((samples[i] >= 0) != (samples[i-1] >= 0)) crossings++;
    return (float)crossings / n;
  }

public:
  bool detect(int16_t* samples, size_t count) {
    return computeRMS(samples, count) > energyThreshold
        && computeZCR(samples, count) < zcrThreshold;
  }
};
```

_Simplified for illustration._

- **Energy (RMS)**: speech has high amplitude; background noise and silence are low. This is
  the primary detector.
- **Zero-Crossing Rate (ZCR)**: hiss, white noise and fans produce frequent zero crossings
  (high ZCR), whereas the voice is a slow, harmonic oscillation (low ZCR). ZCR filters out
  high-frequency interference that RMS alone would let through.

**Self-calibration on boot:** at power-on the device samples 2-3 seconds of ambient noise. The
mean background RMS × 1.8 becomes `energyThreshold`; the mean background ZCR × 1.3 becomes
`zcrThreshold`. A room with an air conditioner running and a quiet room get different
thresholds automatically.

The result: only buffers classified as speech are uploaded. Bandwidth and storage drop by
roughly **3-5×** compared with uploading everything.

### AudioSlot: fixed-length ping-pong buffers in PSRAM

While one chunk is being uploaded over HTTP, I2S capture must not pause. The firmware uses two
fixed-length **AudioSlot** buffers in PSRAM in a ping-pong arrangement:

```
Slot A: [== RECORDING ==] → [== UPLOADING ==] → [== RECORDING ==] → ...
Slot B:                     [== RECORDING ==] → [== UPLOADING ==] → ...
```

Each slot is a fixed PCM buffer plus a state flag (`FREE / RECORDING / READY / UPLOADING`). One
core fills the active slot; when it is full the slot is marked `READY` and capture switches to
the other slot. The second core sees `READY`, performs the HTTP upload, and marks the slot
`FREE` on success. No write blocking, no audio dropped during network latency.

### Dual-core scheduling (FreeRTOS)

| Core | Task | Responsibility |
|---|---|---|
| Core 0 | `captureTask` | I2S DMA read → Adaptive VAD → fill AudioSlot |
| Core 1 | `uploadTask`  | drain READY AudioSlot → HTTP POST with JWT header |

Synchronization is a single counting semaphore: Core 0 calls `xSemaphoreGive` when a slot is
ready; Core 1 blocks on `xSemaphoreTake`. The Wi-Fi stack lives on Core 1, so networking never
interferes with capture.

### Upload protocol

The device **does not stream** audio. It uploads discrete, fixed-length PCM chunks:

- **Speech:** `POST /device/upload/{device_id}` with the raw PCM as
  `application/octet-stream` and a JWT in the `Authorization: Bearer ...` header.
- **Silence:** when the on-chip VAD detects a sustained pause, the device sends a lightweight
  notification to `POST /device/silence`. The backend uses these silence events together with
  the chunk stream to determine where one conversation ends and the next begins.

### Provisioning

**Captive portal (WiFiManager):** on first boot or after a reset the device raises a Wi-Fi
access point named `Ai-Reception-<DEVICE_ID>`. The installer connects from a phone, a captive portal
opens, they enter the venue's SSID and password, and the credentials are saved to NVS.

Captive-portal access points broadcast by the devices, seen from an iPhone

**JWT provisioning:** the device's token is generated in the Telegram MiniApp when a new device
is added, and entered into the device (via the captive portal "Device Token" field). Every
upload is authenticated with that token.

---

## The backend: Swift / Vapor "core"

The backend is a set of small, independent Swift processes. The HTTP-facing **APIServer** is a
Vapor application; each downstream stage is its own worker draining a pgmq queue.

### APIServer: chunk ingestion

For each incoming chunk the APIServer:

1. Verifies the JWT from `Authorization: Bearer ...`.
2. Resolves the device and updates `last_seen_at`.
3. Stores the raw PCM into the **S3 PCM bucket** and writes a chunk-metadata row
   (session, chunk index, speech flag, object key) to Postgres.
4. Watches the chunk + silence-event stream and, when a conversation has clearly ended,
   publishes the session id to the **session queue**.

Session boundaries are decided server-side: the device just reports speech chunks and silence
events; the server recognizes the end-of-conversation pattern.

### SessionWorker: silence trimming and WAV assembly

The SessionWorker consumes a `session_id`, gathers that session's PCM chunks from S3, and
builds a single clean WAV:

- **Silero VAD silence-trimming.** A machine-learning VAD (Silero) runs over the gathered audio
  to remove residual non-speech that the lightweight on-chip Adaptive VAD let through. Short
  internal pauses (natural gaps within a single utterance) are preserved; long gaps become
  region boundaries.
- **WAV assembly.** The retained speech regions are concatenated into one 16 kHz / 16-bit / mono
  WAV and written to the **S3 WAV bucket**.

```swift
func buildWAV(regions: [SpeechRegion]) -> Data {
  let pcm = regions.flatMap { $0.samples }
  let header = WAVHeader(sampleRate: 16000, bitsPerSample: 16, channels: 1, dataSize: pcm.count)
  return header.bytes + Data(pcm)
}
```

_Simplified for illustration._

The two-stage VAD design is intentional: the on-chip Adaptive VAD is a cheap real-time
heuristic that discards ~90% of non-speech for free; Silero is a heavier but far more accurate
ML model that does the final cleanup before the *expensive* transcription call. The session id
is then published to the **transcription queue**.

### TranscriptionWorker: OpenAI Whisper (cloud)

The TranscriptionWorker downloads the cleaned WAV from S3 and sends it to **OpenAI Whisper**
(cloud). The transcript is stored on the session, and the id is published to the **analysis
queue**.

### AnalysisWorker: OpenAI LLM (cloud)

The AnalysisWorker sends the transcript to an **OpenAI LLM** with a structured-output prompt
and stores the returned JSON on the session:

```
System:
You are an analyst of front-desk conversations.
Respond strictly as JSON, with no markdown.

User:
Conversation transcript:
"{transcript}"

Return JSON:
{
  "client_name":    "name if mentioned, otherwise null",
  "visit_purpose":  "purpose of the visit in one phrase",
  "key_questions":  ["question 1", "question 2"],
  "outcome":        "booked | declined | will_call_back | other",
  "sentiment":      "positive | neutral | negative",
  "action_required":"what the owner should do"
}
```

Using the model's JSON / structured-output mode makes parsing reliable. The result is stored as
JSONB and the session is marked `analyzed`, ready to review in the Telegram MiniApp.

---

## Telegram Bot + MiniApp

The owner-facing surface is a Telegram Bot with an embedded **MiniApp** (Vapor + Leaf
templates). It is where reports are delivered and devices are managed.

### Authentication

Every MiniApp request is verified against Telegram's WebApp `initData` using **HMAC-SHA256**, the standard Telegram WebApp scheme, so requests cannot be forged:

```swift
struct TelegramAuthMiddleware: AsyncMiddleware {
  func respond(to request: Request, chainingTo next: AsyncResponder) async throws -> Response {
    guard let initData = request.headers["X-Telegram-Init-Data"].first else {
      throw Abort(.unauthorized)
    }
    let params = initData.split(separator: "&")
    let receivedHash = params.first { $0.hasPrefix("hash=") }?
      .dropFirst("hash=".count).description ?? ""
    let secretKey = HMAC<SHA256>.authenticationCode(
      for: Data("WebAppData".utf8),
      using: SymmetricKey(data: Data(botToken.utf8))
    )
    let dataCheckString = params
      .filter { !$0.hasPrefix("hash=") }
      .sorted()
      .joined(separator: "\n")
    let computed = HMAC<SHA256>.authenticationCode(
      for: Data(dataCheckString.utf8),
      using: SymmetricKey(data: secretKey)
    )
    guard computed == receivedHash else { throw Abort(.unauthorized) }
    return try await next.respond(to: request)
  }
}
```

_Simplified for illustration._

### Screens

**Devices**: a list of the owner's devices with online/offline status (derived from
`last_seen_at`) and a flow to add a new device, which generates the JWT provisioning code.

The mini-app device list with online/offline status

**Sessions**: a chronological feed of conversations. Each card shows the time and duration, the
customer name (from the AI analysis), the visit purpose, the outcome, extracted keyword chips,
and quick access to the audio and the full transcript.

The mini-app feed of analyzed conversations

**Session report**: opening a session in the MiniApp shows its structured report, such as:

```
🏢 AI Reception - Front Desk
⏰ 14:32  •  3 min 21 sec

👤 Customer: Anna
🎯 Purpose: booking a haircut
✅ Outcome: booked for Friday

❓ Asked about:
  • coloring price
  • discounts for regulars

📋 Action: confirm coloring prices with the stylist
```

_Illustration of the mini-app session report view._ Each session in the feed opens its own
detailed report like this.

Beyond the summary, every report carries the full, timestamped transcript: toggle between the
AI-cleaned text and the raw dialogue:

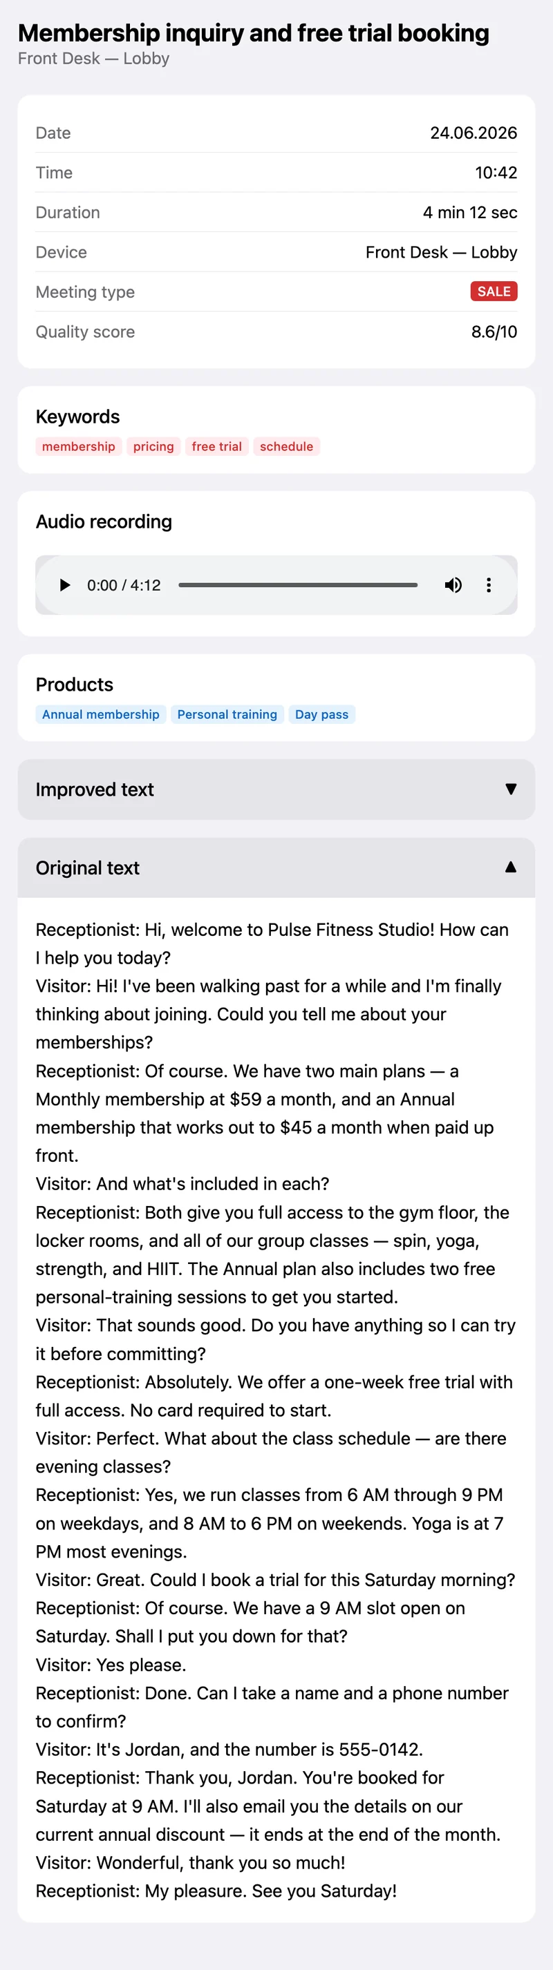
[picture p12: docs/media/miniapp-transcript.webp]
The mini-app full conversation transcript, cleaned and raw views


---

## Data & storage

- **Supabase (Postgres + Auth)** holds the relational data: devices, sessions, and per-chunk
  metadata.
- **S3-compatible buckets** hold the binary audio: one bucket for the raw uploaded **PCM**
  chunks, one for the assembled **WAV** files. Postgres stores only the object keys, keeping
  rows small.
- **Supabase pgmq** provides the three work queues (`session`, `transcription`, `analysis`)
  using nothing but Postgres.

A simplified shape of the core tables:

```sql
create table devices (
  id uuid primary key default gen_random_uuid(),
  owner_telegram_id bigint not null,
  name text not null,
  jwt_token text not null unique,
  last_seen_at timestamptz,
  created_at timestamptz default now()
);

create table sessions (
  id uuid primary key default gen_random_uuid(),
  device_id uuid references devices(id),
  wav_object_key text,            -- S3 WAV bucket
  duration_sec int,
  transcript text,
  analysis jsonb,                 -- structured LLM report
  status text default 'pending',  -- pending → transcribed → analyzed
  started_at timestamptz,
  ended_at timestamptz,
  created_at timestamptz default now()
);

create table chunks (
  id bigserial primary key,
  session_id uuid references sessions(id) on delete cascade,
  device_id uuid references devices(id),
  chunk_index int not null,
  is_speech bool not null,
  pcm_object_key text not null,   -- S3 PCM bucket
  recorded_at timestamptz not null
);

create index on chunks (session_id, chunk_index);
```

_Simplified for illustration; the real schema uses tables such as `pcm_chunks`, `vad_sessions`,
`vad_transcriptions`, and `vad_analysis`._

---

## Hardware & enclosure

The device lives in a **3D-printed round enclosure** designed alongside the firmware so it can
sit cleanly on a reception counter. The housing balances three constraints:
a clear acoustic path to the MEMS microphone, ventilation, and a compact, unobtrusive form
factor.

Multiple enclosure parts were modeled and printed: the base that holds the board, the
perforated grille over the microphone, and the mounting frame:

3D-printed enclosure parts: board base and perforated microphone grille

---

## Project evolution

The current ESP32-S3 system is the third iteration; earlier attempts shaped its design and are
worth a brief note:

- **Gen 1: ESP32 / ESP-IDF (C).** The first prototype wrote raw audio to an SD card and did
  voice-activity detection *server-side*. That meant the device uploaded everything (fans,
  music, silence), the SD card added latency and a data-loss risk on power cuts, and there was
  no device authentication. The clear lesson: VAD belongs on the device, and the buffer belongs
  in RAM, not on a card.
- **Raspberry Pi edge node, abandoned.** A middle attempt put a Raspberry Pi next to the
  reception to run Silero VAD locally (and, optionally, USB-camera capture). It was dropped:
  PyTorch on ARM was heavy, unstable and slow for real-time inference; it required *two* powered
  devices side by side instead of one; and the video path never worked reliably.

Both lessons converged on the current design: move VAD on-chip, eliminate the second box, and
keep only the heavy ML (Silero, Whisper, the LLM) in the backend.

---

## Outcomes

- **End-to-end working system**: a physical device, custom firmware, a queue-driven backend,
  cloud AI, and a Telegram delivery surface, all integrated.
- **Bandwidth cut 3-5×** by doing voice-activity detection on-chip instead of uploading raw
  audio.
- **Resilient by design**: independent workers on a Postgres-native queue mean a failure in one
  stage never takes down the pipeline.
- **Zero staff effort**: the owner reads a concise, structured summary in Telegram seconds after
  each conversation ends.

---

## Tech stack

| Layer | Technology |
|---|---|
| Device | ESP32-S3 · C++ / PlatformIO · FreeRTOS · I2S MEMS mic · Adaptive VAD |
| Transport | HTTP POST (octet-stream PCM chunks) · JWT auth |
| Backend | Swift · Vapor (APIServer + workers) · Leaf (MiniApp templates) |
| Queue | Supabase pgmq (Postgres message queue) |
| Data / Auth  | Supabase (Postgres + Auth) |
| Object store | S3-compatible buckets (PCM, WAV) |
| AI | OpenAI Whisper (transcription) · OpenAI LLM (analysis) · Silero VAD |
| Delivery | Telegram Bot + MiniApp |
| Hardware | 3D-printed round enclosure |
</content>
</invoke>

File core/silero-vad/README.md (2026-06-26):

# Silero VAD microservice

A small FastAPI service that wraps the [Silero VAD](https://github.com/snakers4/silero-vad)
model. It takes one minute of 16 kHz / 16-bit PCM audio and returns a per-second binary
speech mask, so the backend can tell which seconds of a recording contain speech before
spending money on transcription.

## Endpoints

| Method | Path | Description |
|---|---|---|
| `POST` | `/vad` | Body: `{ "pcm_data": [int, ...] }`. Exactly 960000 samples (16000 Hz × 60 s). Returns `{ "speech_mask": [0/1, ...] }` with 60 elements, one per second. |
| `GET`  | `/health` | Liveness/readiness check. Returns model and format info. |

## Run with Docker

The service expects the shared external network and a `SILERO_VAD_PORT` value (see the
parent `core` env). It listens on port `8003` inside the container.

```bash
# from core/silero-vad
docker compose up -d --build
```

Or build and run the image directly:

```bash
docker build -t silero-vad .
docker run -p 8003:8003 silero-vad
```

The Silero model is pre-downloaded at image build time to keep startup fast.

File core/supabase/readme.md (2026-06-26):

# Supabase (database)

This folder holds the Supabase project for the backend: the database schema as ordered SQL
migrations plus a seed file for local development.

## Layout

- `config.toml`: Supabase CLI project configuration.
- `migrations/`: timestamped SQL migrations (the source of truth for the schema).
- `seed.sql`: sample data loaded into a fresh local database.

## Apply

Requires the [Supabase CLI](https://supabase.com/docs/guides/cli).

```bash
# Start the local stack (applies migrations + seed.sql)
supabase start

# Compare local schema against the migrations
supabase db diff

# Generate a new migration from local changes
supabase db diff -f <name>

# Push migrations to the linked remote project
supabase db push
```

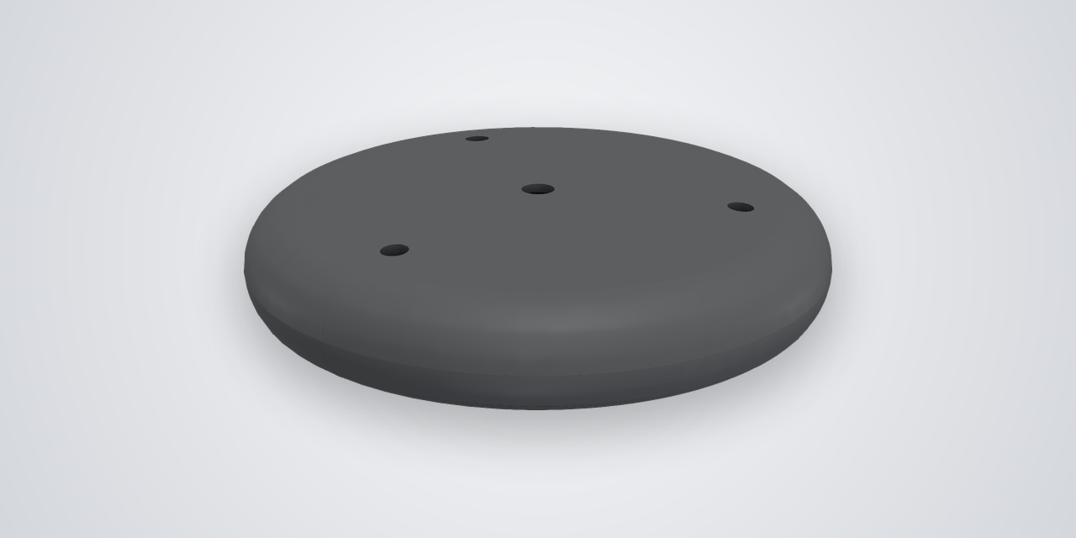
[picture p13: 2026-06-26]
assets/social-preview.png

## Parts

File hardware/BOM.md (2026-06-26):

# AI Reception - Bill of Materials (Reference)

> **Honesty note.** This BOM is **derived from the firmware**, not from a
> published schematic. The repository ships firmware, CAD, and backend. It does
> **not** include an electrical schematic, a PCB, or a wiring diagram. The board,
> the GPIO assignments, and the audio configuration below are **certain** because
> they come straight from `firmware/platformio.ini` and the firmware source. The
> **specific microphone part, the microSD module, connectors, and passives are
> NOT specified anywhere in the repo**. They are marked **"reference /
> representative"** and are educated suggestions for a part that would satisfy
> the firmware's requirements. Treat anything labeled *reference* as a starting
> point to verify against your real build, not as the exact component used.

See [`hardware/README.md`](README.md) for the 3D-printed enclosure and
print settings, and [`docs/architecture.md`](../docs/architecture.md) for how the
hardware fits the full system.

---

## 1. What the firmware actually requires

These facts are load-bearing and taken directly from the source:

| Requirement | Value | Source |
|---|---|---|
| MCU board | ESP32-S3 **N16R8** (`4d_systems_esp32s3_gen4_r8n16`), 16 MB flash / 8 MB PSRAM | `platformio.ini` (`board`, `board_upload.flash_size = 16MB`, `psram_type = opi`) |
| PSRAM | Required (`-DBOARD_HAS_PSRAM`); two ~1.83 MB audio slots allocated in PSRAM | `platformio.ini`, `audio_system.cpp` |
| USB | Native USB CDC on boot (`ARDUINO_USB_MODE=1`, `ARDUINO_USB_CDC_ON_BOOT=1`) | `platformio.ini` |
| Microphone interface | I2S, MEMS, **mono / left channel**, 16 kHz, 32-bit I2S slots (downsampled to 16-bit PCM) | `i2s_mic.cpp` (`I2S_CHANNEL_FMT_ONLY_LEFT`), `platformio.ini` |
| Reset / re-provision button | Momentary, on **GPIO18**, `INPUT_PULLUP` (active-low) | `platformio.ini` (`RESET_BUTTON_PIN=18`), `main.cpp` |
| Power | USB-C (board-supplied); firmware watches for brownout resets | `check_and_send_crash_log()` handles `ESP_RST_BROWNOUT` |

The firmware drives an I2S MEMS microphone and reads one button. There is **no
code** that references an SD card, an LED, a battery gauge, or any other
peripheral. The microSD-over-SPI line below is therefore **purely a reference
option**, included because the task asked for it: *the firmware does not use
microSD.*

---

## 2. Bill of materials

Legend: **Exact** = pinned by the firmware/repo · **Reference** = representative
suggestion, verify against your real build.

| # | Component | Suggested part | Qty | Confidence | Notes |
|---|---|---|---|---|---|
| 1 | **MCU dev board** | ESP32-S3 **N16R8** module/dev board (16 MB flash, 8 MB OPI PSRAM); PlatformIO board id `4d_systems_esp32s3_gen4_r8n16` | 1 | **Exact (board id)** / Reference (exact vendor board) | Any ESP32-S3 N16R8 board with exposed I2S-capable GPIOs 15/16/17 and a USB-C port works. The PlatformIO board id is a definition match, not necessarily the physical board purchased. |
| 2 | **I2S MEMS microphone** | INMP441 (or ICS-43434 / SPH0645LM4H) I2S MEMS mic breakout | 1 | **Interface exact, part Reference** | Firmware needs an I2S mic, mono, 16 kHz, std-I2S format. INMP441 is the most common 24-bit I2S MEMS mic on a breakout and matches the `>> 11` scaling / 32-bit slot reads. The exact mic is **not specified in the repo**. |
| 3 | **Reset / re-provision button** | Momentary tactile push button (SPST, normally-open) | 1 | **Pin exact (GPIO18), part Reference** | Wired GPIO18 ↔ GND; firmware uses internal pull-up. Short press = noop, long press (>3 s) = clear Wi-Fi + reboot. |
| 4 | **USB-C cable + 5 V supply** | USB-C data/power cable, 5 V phone-style adapter | 1 | **Interface exact, part Reference** | Powers and flashes the board over native USB. No on-board battery in firmware. |
| 5 | **microSD module (SPI)** | microSD breakout over SPI + microSD card | 0-1 | **Reference / NOT USED** | Requested in the task as "if present." **The firmware contains no SD-card code**. Include only if you add local logging yourself. Listed for completeness, not because the device needs it. |
| 6 | **Hook-up wiring / headers** | Dupont jumpers or soldered wires; pin headers | as needed | Reference | For mic ↔ board and button ↔ board. |
| 7 | **Enclosure (3D-printed)** | `mic-v7-main.step` (round body) + `mic-v7-case-mic-hole.step` (cap / front cover with the mic hole) | 1 set | **Exact (in repo)** | PLA, ~0.2 mm layers, 15-20% infill, see [`hardware/README.md`](README.md). |

> Passives (decoupling caps, pull-up/pull-down resistors beyond the MCU's
> internal pull-ups), screws, and adhesives are **not** specified in the repo and
> are left to the builder. None are referenced by the firmware.

---

## 3. Wiring / pin table

All pin assignments are **exact**: pulled verbatim from the `build_flags` in
[`firmware/platformio.ini`](../firmware/platformio.ini) and confirmed in
`firmware/src/i2s/i2s_mic.cpp` and `firmware/src/main.cpp`.

### I2S MEMS microphone → ESP32-S3

| Signal | Build flag | GPIO | I2S role |
|---|---|---|---|
| Serial data (mic → ESP) | `I2S_SD_GPIO` | **15** | `data_in_num` (SD / DOUT) |
| Word select (LRCLK) | `I2S_WS_GPIO` | **16** | `ws_io_num` (WS / LRCL) |
| Bit clock (BCLK) | `I2S_SCK_GPIO` | **17** | `bck_io_num` (SCK / BCLK) |
| Power | - | 3V3 | Mic VDD |
| Ground | - | GND | Mic GND |
| Channel select (L/R) | - | GND* | *Reference:* tie to GND for left channel, firmware uses `I2S_CHANNEL_FMT_ONLY_LEFT`. Pin name is mic-specific. |

I2S driver config (`i2s_mic.cpp`): `I2S_NUM_0`, master + RX, std-I2S comm
format, left-channel-only, `dma_buf_count = 8`, `dma_buf_len = 512`.

### Button → ESP32-S3

| Signal | Build flag | GPIO | Wiring |
|---|---|---|---|
| Reset / re-provision | `RESET_BUTTON_PIN` | **18** | Button between GPIO18 and GND; `INPUT_PULLUP`, active-low. |

### Audio configuration (firmware constants, exact)

| Setting | Build flag | Value |
|---|---|---|
| Sample rate | `I2S_SAMPLE_RATE` | 16000 Hz |
| Bits per I2S slot | `I2S_BITS_PER_SAMPLE` | 32 (stored/uploaded as 16-bit PCM) |
| Capture buffer | `I2S_BUFFER_SAMPLES` | 256 samples |
| DMA buffers | `I2S_DMA_BUF_COUNT` / `I2S_DMA_BUF_LEN` | 8 / 512 |
| Slot duration | `AUDIO_RECORD_DURATION_SEC` | 60 s (≈1.83 MB per slot in PSRAM) |
| PSRAM budget | `PSRAM_USAGE_PERCENT` | 80% |
| Slot pool bounds | `MIN_BUFFER_SLOTS` / `MAX_BUFFER_SLOTS` | 2 / 10 |
| Captive-portal AP | `WIFI_AP_SSID` | `Ai-Reception-<DEVICE_ID>` (open) |

---

## 4. ASCII wiring sketch (reference)

```
   I2S MEMS mic (e.g. INMP441 - reference part)        ESP32-S3 N16R8
   ┌──────────────┐                                    ┌──────────────┐
   │ VDD          ├────────────── 3V3 ─────────────────┤ 3V3          │
   │ GND          ├────────────── GND ─────────────────┤ GND          │
   │ SD  (DOUT)   ├──────────────────────────── GPIO15 ┤ I2S_SD       │
   │ WS  (LRCL)   ├──────────────────────────── GPIO16 ┤ I2S_WS       │
   │ SCK (BCLK)   ├──────────────────────────── GPIO17 ┤ I2S_SCK      │
   │ L/R   ──► GND (left channel)                       │              │
   └──────────────┘                                    │              │
                                                        │              │
   Momentary button                                     │              │
   ┌──────────────┐                                     │              │
   │  ┌─o o─┐     ├──────────────────────────── GPIO18 ┤ RESET_BUTTON │
   │  └─────┘     ├────────────── GND ─────────────────┤ GND          │
   └──────────────┘                                     │  USB-C ◄── 5V power / flash
                                                        └──────────────┘
```

---

## 5. 3D-print notes

Printable enclosure source files live in `hardware/`. From
[`hardware/README.md`](README.md):

- **Material:** PLA
- **Layer height:** ~0.2 mm
- **Infill:** 15-20%
- **Supports:** as needed (depends on part orientation)
- **Formats:** `.step` (parametric CAD source, edit in Fusion/FreeCAD/SolidWorks/Onshape)

Parts: enclosure `enclosure/mic-v7-main.step` (round body) +
`enclosure/mic-v7-case-mic-hole.step` (cap / front cover with the mic hole).

---

## 6. Summary of inferences (read this)

| Item | Status |
|---|---|
| ESP32-S3 N16R8 board, GPIO 15/16/17/18, USB-C, PSRAM, 16 kHz mono I2S | **Confirmed from firmware**, not inferred |
| Specific microphone model (INMP441 etc.) | **Inferred**, repo only specifies "I2S MEMS mic," not a part number |
| Mic L/R-select pin wiring | **Inferred**, pin name/position is mic-specific; left-channel requirement is exact |
| microSD-over-SPI module | **Inferred & NOT USED**, no SD code exists in the firmware |
| USB-C power supply / cable spec | **Inferred**, board uses native USB; exact PSU not specified |
| Passives, connectors, fasteners, adhesives | **Inferred / builder's choice**, none referenced in the repo |
| Enclosure, print settings, pin map, audio config | **Confirmed from repo** |

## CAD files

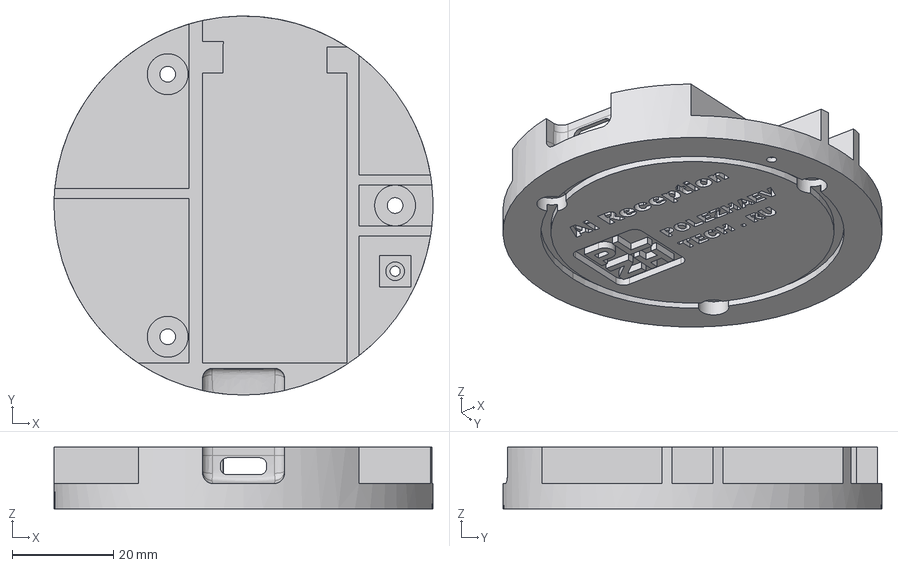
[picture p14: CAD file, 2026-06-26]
hardware/enclosure/mic-v7-main.step
75.0 x 75.0 x 12.2 mm

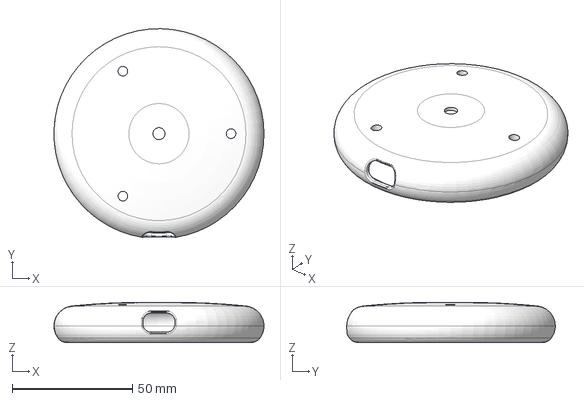
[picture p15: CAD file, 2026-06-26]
hardware/enclosure/mic-v7-case-mic-hole.step
87.4 x 86.8 x 16.7 mm

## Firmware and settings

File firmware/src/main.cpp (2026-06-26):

// main.cpp - Firmware entry point: boot, WiFi provisioning, auth, and audio tasks.
#include <Arduino.h>
#include <WiFi.h>
#include <WiFiManager.h>
#include <esp_log.h>

#include "audio/audio_system.h"
#include "i2s/i2s_mic.h"
#include "portal/portal.h"
#include "boot/boot_auth.h"
#include "server/server_api.h"

char jwt_token[512] = {0};
I2SMic microphone;

void setup() {
    delay(1000);
    Serial.begin(115200);
    delay(1000);

    ESP_LOGI("SETUP", "AI-Reception ESP32-S3");

    pinMode(RESET_BUTTON_PIN, INPUT_PULLUP);

    if (!init_audio_memory()) ESP.restart();

    WiFiManager wm;
    portal_start(wm);

    uint32_t server_time;
    if (!boot_auth(jwt_token, sizeof(jwt_token), &server_time)) ESP.restart();
    set_system_time(server_time);

    // Check and send crash log if one occurred
    check_and_send_crash_log();

    if (!microphone.begin() || !init_audio_tasks()) ESP.restart();

    ESP_LOGI("SETUP", "Done");
}

void loop() {
    static unsigned long last_stats = 0;
    static bool pressed = false;
    static unsigned long start = 0;
    static bool long_press_handled = false;

    // Reset / recalibration button
    if (digitalRead(RESET_BUTTON_PIN) == LOW) {
        if (!pressed) {
            pressed = true;
            start = millis();
            long_press_handled = false;
        } else {
            unsigned long hold_time = millis() - start;

            // Long press (3+ sec) - reset WiFi
            if (hold_time > 3000 && !long_press_handled) {
                ESP_LOGI("MAIN", "🗑️ Long press - reset WiFi");
                WiFiManager wm;
                wm.resetSettings();
                ESP.restart();
            }
        }
    } else {
        pressed = false;
        long_press_handled = false;
    }

    delay(100);
}

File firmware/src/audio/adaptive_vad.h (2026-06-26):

// adaptive_vad.h - Fully adaptive VAD with calibration
#pragma once
#include <cstdint>
#include <algorithm>
#include <cmath>

enum VADState {
    VAD_CALIBRATING,    // Calibration at startup
    VAD_RUNNING,        // Normal operation
    VAD_RECALIBRATING   // Recalibration every hour
};

struct VADStats {
    float background_mean;      // Background mean value
    float background_variance;  // Background variance
    float background_std;       // Standard deviation
    int samples_collected;      // Samples collected for statistics
};

class AdaptiveVAD {
private:
    // Adaptation parameters
    static constexpr int CALIBRATION_SAMPLES = 500;      // Samples for calibration
    static constexpr int BACKGROUND_HISTORY = 1000;      // Background history size
    static constexpr float CHANGE_THRESHOLD = 3.0f;      // Sigma for change detection
    static constexpr float ZCR_MIN = 0.03f;             // Minimum ZCR for speech
    static constexpr float ZCR_MAX = 0.4f;              // Maximum ZCR for speech
    static constexpr unsigned long RECALIB_INTERVAL = 3600000; // 1 hour in ms

    // State
    VADState state_;
    unsigned long last_calibration_;

    // Background statistics
    VADStats stats_;
    float background_history_[BACKGROUND_HISTORY];
    int history_index_;
    int calibration_count_;

    // Temporal filtering
    int speech_frames_;
    int silence_frames_;
    static constexpr int MIN_SPEECH_FRAMES = 3;

    // Methods
    float calculate_energy(const int16_t* samples, size_t count);
    float calculate_zcr(const int16_t* samples, size_t count);
    void update_background_stats(float energy);
    void start_calibration();
    bool is_significant_change(float energy);
    float calculate_mean(float* data, int count);
    float calculate_variance(float* data, int count, float mean);

public:
    AdaptiveVAD();
    bool detect_speech(const int16_t* samples, size_t count);
    void reset_speech_state();  // Reset speech state between recordings
    VADState get_state() const { return state_; }
    VADStats get_stats() const { return stats_; }
    bool is_calibrated() const { return state_ == VAD_RUNNING; }
};

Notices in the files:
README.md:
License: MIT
